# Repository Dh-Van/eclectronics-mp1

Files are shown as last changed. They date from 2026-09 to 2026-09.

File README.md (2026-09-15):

# ENGR 3430 Miniproject 1 – USB LED Flasher

A USB-stick style board that plugs into a USB-A port, regulates 5 V down to 3.3 V, and blinks a red LED with a 1 s period using an op-amp relaxation oscillator.

## Folder layout

| Folder | What's in it |
|---|---|
| `kicad/` | KiCad 10 project: schematic, PCB layout, project settings. `kicad/lib/` holds the custom symbol library (`Eclectronics.kicad_sym`) and footprints (`Eclectronics.pretty/`) for the USB plug, MCP1702 and MCP6021. The project's `sym-lib-table` / `fp-lib-table` point at these with `${KIPRJMOD}` paths, so the project opens on any machine with no extra setup. |
| `ltspice/` | LTspice simulation. `sim.asc` is the 500-run Monte Carlo of the oscillator period (1 % resistors, 5 % cap); `sim.log` has the measured period for every run. The 290 MB `sim.raw` waveform file is not committed – rerun `sim.asc` to regenerate it. |
| `docs/` | `MP1_report.md` / `MP1_report.pdf` (design choices + period analysis; `build_pdf.py` regenerates the PDF with lualatex), `MP1_BOM.csv`, `MP1_schematic.pdf`, the assignment PDF and the allowed parts list. |

## Key numbers

- Period: 1.000 s by hand calculation, 0.987 s mean in simulation, worst case -6.8 % / +7.1 % (spec is +/-10 %).
- Board: 2 layers, 16.1 mm x 14.0 mm, all parts on top, back side is a ground pour. DRC clean.

## Opening the project

Open `kicad/MP1.kicad_pro` in KiCad 10. Note: the LTspice sim names differ from the KiCad schematic (sim R4 = KiCad R5, sim R5 = KiCad R4, sim C1 = KiCad C4); see the report.

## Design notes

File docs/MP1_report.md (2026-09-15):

# MP1 – USB LED Flasher: Design Choices and Period Analysis

## 1. Overview

The board plugs straight into a USB-A port, drops the 5 V to 3.3 V, and uses an op-amp relaxation oscillator to blink a red LED with a 1 s period.

$$
\text{USB 5 V} \;\rightarrow\; \text{3.3 V regulator (U1)} \;\rightarrow\; \text{op-amp oscillator (U2)} \;\rightarrow\; \text{R6 + LED}
$$

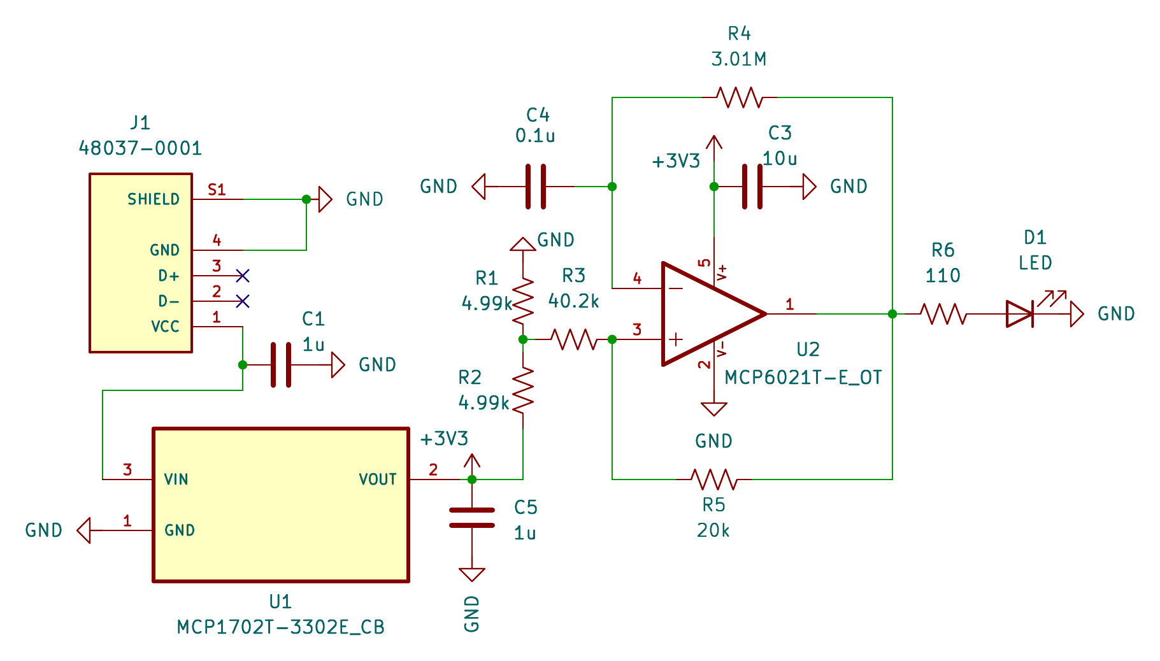
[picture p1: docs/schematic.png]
Circuit schematic. J1 is the USB-A plug, U1 the 3.3 V regulator, U2 the op-amp oscillator, D1 the LED. Full-size copy in .


Only parts from the provided parts list were allowed. That list has one connector, one regulator, two op-amps (single/dual versions of the same part), three LED colours, seven capacitor values and a set of 1% resistors. So most parts had no alternative; the real choices were the oscillator topology, the timing values, single vs. dual op-amp, and the LED colour. Part names are the KiCad ones (the LTspice sim uses sim R4 = KiCad R5, sim R5 = KiCad R4, sim C1 = KiCad C4).

**Why an op-amp oscillator.** There is no 555, microcontroller or crystal on the list, so the timer has to be built from the op-amp. A relaxation oscillator (Schmitt trigger + RC) needs one op-amp, one capacitor and a few resistors, gives a square wave that drives the LED directly, and has a simple period formula, which makes the tolerance analysis clean.

## 2. Power supply

- **J1 – Molex 48037-0001 USB-A plug.** Only connector on the list. Only VBUS and GND are used; D+/D- are left open since the board only takes power. Average draw is about 7 mA (1 mA op-amp + 12 mA LED half the time), well under the 100 mA a port gives without enumeration.
- **U1 – MCP1702 3.3 V LDO.** Only regulator on the list; fixed 3.3 V so no setting resistors; 250 mA rating vs. 7 mA used. Dissipation is about 12 mW.
- **C1 = 1 uF in, C3 = 10 uF out.** The MCP1702 datasheet needs at least 1 uF ceramic on both pins. The list only has 1 uF and 10 uF; the 10 uF goes on the output because that rail feeds everything and supplies the 12 mA LED step.
- **C5 = 1 uF op-amp bypass**, right at the V+ pin. The datasheet suggests 0.1-1 uF; 1 uF holds the pin steadier during the LED step, and it keeps the 0.1 uF (the only 5% cap) free for the timer.

## 3. Oscillator

**U2 – MCP6021.** Single op-amp in SOT-23-5. The MCP6022 is the same part but dual; only one is needed, so the single is smaller and leaves no unused op-amp. It works here because it runs on a single 3.3 V supply, has rail-to-rail output (the timing math assumes the output sits at the rails), has ~1 pA input current (negligible against the ~1 uA timing current), and can drive ~30 mA so no LED transistor is needed.

**How it works.** R1/R2 (4.99 k each) make a 1.65 V mid-rail reference $V_{mid}$, needed because there is no negative supply. R3 (40.2 k) and R5 (20 k) feed the + input from $V_{mid}$ and the output, giving two thresholds either side of $V_{mid}$. R4 (3.01 M) charges C4 (0.1 uF) on the - input from the output. When C4 crosses the upper threshold the output flips low and C4 discharges; when it crosses the lower threshold the output flips high again. The output is a square wave and the LED follows it.

**Why these values.**

- **C4 = 0.1 uF.** The period is proportional to $R_4 C_4$, so the cap tolerance goes straight into the period. On the list the 0.1 uF is 5% ("J" in the part number); the 1 uF and 10 uF are 10%, which would fail the spec (Section 5.3); the 1% C0G parts (1 nF and below) would need a 300 M resistor, and the list stops at 10 M.
- **R4 = 3.01 M.** Gives $R_4 C_4 = 0.301$ s and a period of 1.00 s with the thresholds below. 10 M would need thresholds within 20 mV of the rails; 2 M works but pushes the thresholds much closer to the rails than 3.01 M.
- **R3 = 40.2 k, R5 = 20 k.** Thresholds too close to the rails make the period sensitive to how close the output really gets to the rails; too close to $V_{mid}$ makes the cap swing small so offset (0.5 mV) and noise matter. The 2:1 ratio puts the thresholds about 0.5 V from each rail, a good compromise.
- **R1 = R2 = 4.99 k.** Equal values give exactly half the supply, so the two half-cycles are equal (50% duty). 4.99 k is stiff enough that R3 barely loads it, and wastes only 0.3 mA.

## 4. LED

**D1 red LED (LTST-C171KRKT), R6 = 110 Ohm.** Red has the lowest forward voltage (~2 V) of the three LEDs, so on 3.3 V it gets the most current; green/blue (~3 V) would only get a few mA. The LED is driven straight from the output (anode to op-amp, cathode to ground), so it is on for half of each period:

$$
I_{LED} = \frac{3.3 - V_f}{R_6} = \frac{3.3 - 2.0}{110} \approx 12\ \text{mA}
$$

That is bright, with margin under the LED's 20 mA and the op-amp's ~30 mA limits. The 12 mA load pulls the high output down by ~0.1-0.2 V; that makes the charge half slightly longer and the discharge half slightly shorter, and the two nearly cancel (about +0.1% on the period, duty 50% to 52%).

## 5. Period analysis

### 5.1 Thresholds and period

The divider gives $V_{mid} = 1.65$ V and looks like $R_1 \parallel R_2 = 2.5$ k in series with R3, so the effective resistor from $V_{mid}$ to the + input is $R_a = 40.2 + 2.5 = 42.7$ k. The + input is a weighted average of $V_{mid}$ (through $R_a$) and the output (through $R_5$):

$$
V_{high} = \frac{V_{mid} R_5 + 3.3\,R_a}{R_a + R_5} = 2.774\ \text{V}, \qquad
V_{low} = \frac{V_{mid} R_5}{R_a + R_5} = 0.526\ \text{V}
$$

These are symmetric about 1.65 V. Charging from $V_{low}$ to $V_{high}$ with the output at 3.3 V, and discharging back, each take

$$
t_{up} = R_4 C_4 \ln\!\left(\frac{3.3 - V_{low}}{3.3 - V_{high}}\right)
      = 0.301 \cdot \ln\!\left(\frac{2.774}{0.526}\right) = 0.500\ \text{s},
\qquad
t_{down} = R_4 C_4 \ln\!\left(\frac{V_{high}}{V_{low}}\right) = 0.500\ \text{s}
$$

$$
T = t_{up} + t_{down} = 2 R_4 C_4 \ln\!\left(\frac{1 + \beta}{1 - \beta}\right) = 1.000\ \text{s}, \qquad \beta = \frac{R_a}{R_a + R_5} = 0.681
$$

(Leaving out the divider's 2.5 k gives 0.971 s, so it matters.)

### 5.2 Sensitivity

| Part | Change | Effect on $T$ |
|---|---|---|
| R4 (3.01 M) | +1% | +1.00% |
| C4 (0.1 uF) | +5% | +5.00% |
| R3 (40.2 k) | +1% | +0.46% |
| R5 (20 k) | +1% | -0.48% |
| R1 or R2 | +1% | +0.01% |

The period is essentially $R_4 C_4$; the threshold resistors count about half; the divider barely matters because shifting $V_{mid}$ lengthens one half-cycle and shortens the other. With 1% resistors, almost the whole error budget is the 5% cap.

### 5.3 Worst case

Stacking every tolerance the same way: $T = 1.071$ s (+7.1%) or $T = 0.932$ s (-6.8%). Both are inside +/-10% with about 3% to spare. With a 10% cap the worst case would be about +/-12% and fail, which is why the 5% 0.1 uF was chosen. Other effects are small: output 25 mV short of the rails (<0.1%), LED load droop (+0.1%), 0.5 mV input offset (0.02%), 1 pA bias current (negligible), 100 ppm/C resistors over 20 C (0.2%).

### 5.4 Monte Carlo (LTspice)

The sim uses the generic `UniversalOpAmp2` (no MCP6021 model exists) on a 3.3 V single supply, `.ic V(vn)=0` for a repeatable start, and measures the time between the 2nd and 3rd rising edges to skip the startup transient. `.step param run 1 500 1` with `mc(value, 0.01)` on every resistor and `mc(0.1u, 0.05)` on C4 gives 500 runs with the real part tolerances.

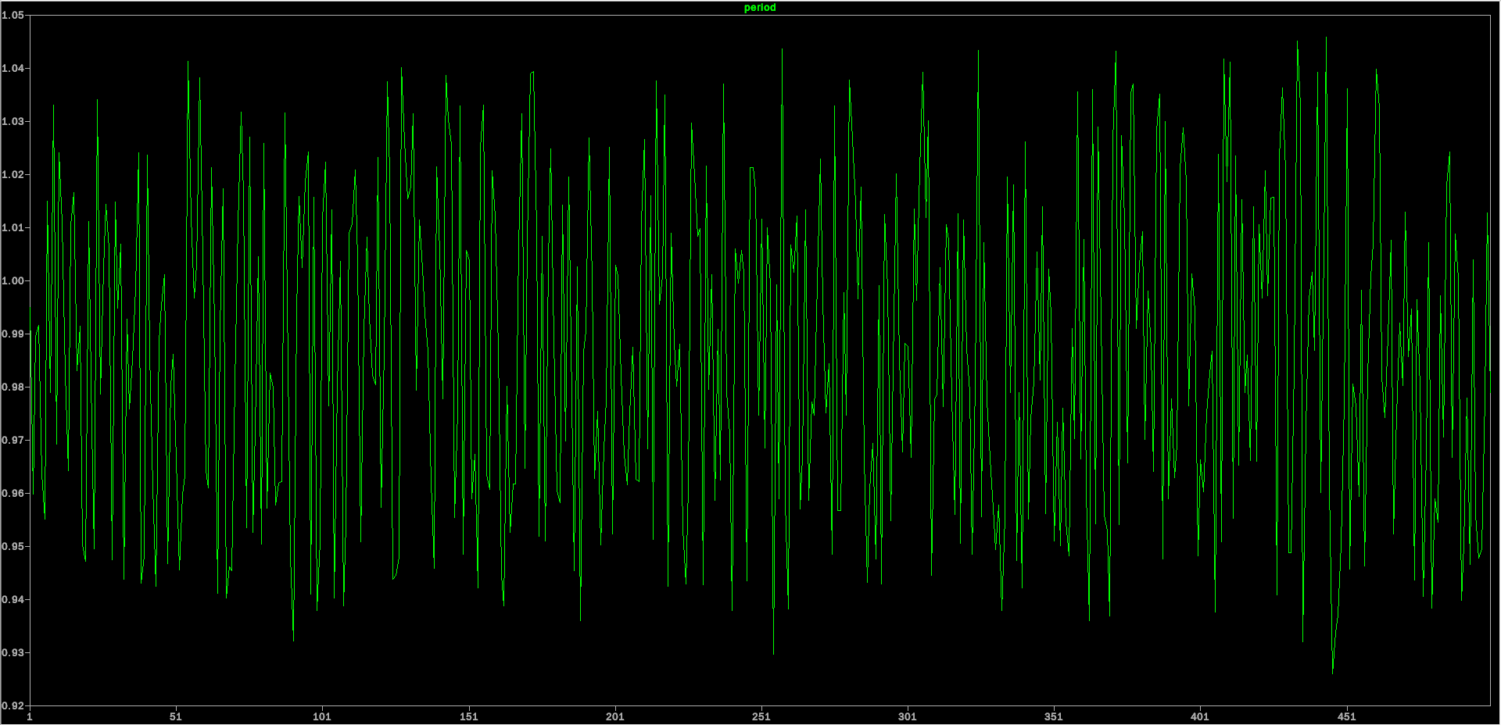
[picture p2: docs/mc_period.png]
Period of each Monte Carlo run. The y-axis spans 0.92-1.05 s; the +/-10% limits are 0.9 s and 1.1 s, so every run is inside.


| Statistic | Value |
|---|---|
| Mean period | 0.987 s |
| Std. deviation | 0.030 s |
| Minimum | 0.926 s (-7.4%) |
| Maximum | 1.046 s (+4.6%) |
| Runs inside 0.9-1.1 s | 500 / 500 |

The mean is 1.4% under the hand value because the modelled op-amp does not switch instantly or sit exactly on the rails. Every run is inside the window, matching the worst-case math.

## 6. PCB

- **Size.** 16.1 x 14.0 mm (225 mm^2). Height is set by the plug's shield pads plus edge clearance; width by fitting the parts in columns beside the plug. The board edge sits on the line the Molex footprint marks for it, and the plug is centred.
- **Placement.** U1 sits at J1's VBUS pin (2.4 mm trace) with C1 and C3 at its pins. U2 is in the middle with R3/C4 to its left, R5 above, R4 below, so the high-impedance - input trace is ~2 mm. C5 is at the V+ pin. R6 and D1 are at the far end so the LED is visible when plugged in.
- **Layers.** Two layers, all parts on top. Everything is routed on top; the back is an unbroken ground pour. Each ground pad reaches it through a via (0.8 mm / 0.4 mm drill); nearby grounds (U1, C1, C3, D1) share one. No via is in or touching a pad, to avoid paste wicking and tombstoning. The plug's through-hole pads join the pour with thermal reliefs. There is no top pour.
- **The one crossing.** The op-amp pinout forces one trace crossing. Instead of a back-side jumper (which would slot the ground plane), the 3.3 V feed to V+ runs between R4's pads.
- **Trace widths.** Power is 0.5 mm (20 mil), signals 0.2 mm (8 mil), 0.2 mm clearance, vias 31/16 mil, all above the 6 mil / 24-12 mil minimums. The one exception is the 3.3 V branch to the op-amp V+ pin: it narrows to 0.3-0.4 mm for ~4 mm because the gap between R4's pads is only 0.85 mm and a 0.5 mm trace would violate clearance. That branch carries about 1 mA, so it makes no difference.
- **Silkscreen / fab.** 0.8 mm reference designators kept off all pads; the plug's off-board silk outline removed; F.Fab has outlines, references and values for assembly; the back silk has the board name, author and revision.
- **Checks.** DRC: 0 errors, 0 warnings, 0 unconnected. Schematic/PCB parity clean. Footprints are imperial 0603/0805, SOT-23-3 and SOT-23-5 as on the parts list. IC pin numbers match the datasheets (MCP1702: 1 GND, 2 VOUT, 3 VIN; MCP6021: 1 OUT, 2 VSS, 3 IN+, 4 IN-, 5 VDD).

## 7. Bill of materials

All parts are from the provided parts list: 12 line items, 15 parts. (Also provided as `MP1_BOM.csv`.)

| # | Ref | Qty | Value | Description | Manufacturer Part # | Digi-Key # | Tol. | Notes |
|---|---|---|---|---|---|---|---|---|
| 1 | J1 | 1 | 48037-0001 | CONN PLUG USB 4POS RT ANG PCB | 0480370001 | WM17117-ND |  | USB-A plug; only VBUS and GND used |
| 2 | U1 | 1 | MCP1702T-3302E/CB | IC REG LIN 3.3V 250MA SOT23A-3 | MCP1702T-3302E/CB | MCP1702T-3302E/CBCT-ND |  | 3.3 V LDO regulator |
| 3 | U2 | 1 | MCP6021T-E/OT | IC OPAMP GP 10MHZ RRO SOT23-5 | MCP6021T-E/OT | MCP6021T-E/OTCT-ND |  | Rail-to-rail op-amp (oscillator) |
| 4 | D1 | 1 | LED | LED RED CLEAR 0805 SMD | LTST-C171KRKT | 160-1427-1-ND |  | Red LED |
| 5 | C1,C5 | 2 | 1u | CAP CER 1UF 25V X7R 0603 | C0603C105K3RACTU | 399-7376-1-ND | 10% | C1 = LDO input cap; C5 = op-amp bypass |
| 6 | C3 | 1 | 10u | CAP CER 10UF 16V X5R 0603 | GRT188R61C106KE13D | 490-12317-1-ND | 10% | LDO output / bulk cap |
| 7 | C4 | 1 | 0.1u | CAP CER 0.1UF 50V X7R 0603 | CC0603JRX7R9BB104 | 311-1779-1-ND | 5% | Timing capacitor |
| 8 | R1,R2 | 2 | 4.99k | RES SMD 4.99K OHM 1% 1/10W 0603 | RC0603FR-074K99L | 311-4.99KHRCT-ND | 1% | Mid-rail divider |
| 9 | R3 | 1 | 40.2k | RES SMD 40.2K OHM 1% 1/10W 0603 | RC0603FR-0740K2L | 311-40.2KHRCT-ND | 1% | Threshold resistor |
| 10 | R4 | 1 | 3.01M | RES SMD 3.01M OHM 1% 1/10W 0603 | RC0603FR-073M01L | 311-3.01MHRCT-ND | 1% | Timing resistor |
| 11 | R5 | 1 | 20k | RES SMD 20K OHM 1% 1/10W 0603 | RC0603FR-0720KL | 311-20.0KHRCT-ND | 1% | Threshold / positive feedback resistor |
| 12 | R6 | 1 | 110 | RES SMD 110 OHM 1% 1/10W 0603 | RC0603FR-07110RL | 311-110HRCT-ND | 1% | LED current-limit resistor |

**Project files.** All KiCad design files, the custom symbol/footprint library, the LTspice simulation, this report and the BOM are at:

https://github.com/Dh-Van/eclectronics-mp1

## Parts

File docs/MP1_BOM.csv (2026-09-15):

Item | Reference | Qty | Value | Description | Package | Manufacturer | Manufacturer Part # | Digi-Key Part # | Tolerance | Notes
1 | J1 | 1 | 48037-0001 | CONN PLUG USB 4POS RT ANG PCB | Through-hole right angle | Molex | 0480370001 | WM17117-ND |  | USB-A plug; only VBUS and GND used
2 | U1 | 1 | MCP1702T-3302E/CB | IC REG LIN 3.3V 250MA SOT23A-3 | SOT-23-3 | Microchip | MCP1702T-3302E/CB | MCP1702T-3302E/CBCT-ND |  | 3.3 V LDO regulator
3 | U2 | 1 | MCP6021T-E/OT | IC OPAMP GP 10MHZ RRO SOT23-5 | SOT-23-5 | Microchip | MCP6021T-E/OT | MCP6021T-E/OTCT-ND |  | Rail-to-rail op-amp (oscillator)
4 | D1 | 1 | LED | LED RED CLEAR 0805 SMD | 0805 | Lite-On | LTST-C171KRKT | 160-1427-1-ND |  | Red LED
5 | C1,C5 | 2 | 1u | CAP CER 1UF 25V X7R 0603 | 0603 | KEMET | C0603C105K3RACTU | 399-7376-1-ND | 10% | C1 = LDO input cap; C5 = op-amp bypass
6 | C3 | 1 | 10u | CAP CER 10UF 16V X5R 0603 | 0603 | Murata | GRT188R61C106KE13D | 490-12317-1-ND | 10% | LDO output / bulk cap
7 | C4 | 1 | 0.1u | CAP CER 0.1UF 50V X7R 0603 | 0603 | Yageo | CC0603JRX7R9BB104 | 311-1779-1-ND | 5% | Timing capacitor
8 | R1,R2 | 2 | 4.99k | RES SMD 4.99K OHM 1% 1/10W 0603 | 0603 | Yageo | RC0603FR-074K99L | 311-4.99KHRCT-ND | 1% | Mid-rail divider
9 | R3 | 1 | 40.2k | RES SMD 40.2K OHM 1% 1/10W 0603 | 0603 | Yageo | RC0603FR-0740K2L | 311-40.2KHRCT-ND | 1% | Threshold resistor
10 | R4 | 1 | 3.01M | RES SMD 3.01M OHM 1% 1/10W 0603 | 0603 | Yageo | RC0603FR-073M01L | 311-3.01MHRCT-ND | 1% | Timing resistor
11 | R5 | 1 | 20k | RES SMD 20K OHM 1% 1/10W 0603 | 0603 | Yageo | RC0603FR-0720KL | 311-20.0KHRCT-ND | 1% | Threshold / positive feedback resistor
12 | R6 | 1 | 110 | RES SMD 110 OHM 1% 1/10W 0603 | 0603 | Yageo | RC0603FR-07110RL | 311-110HRCT-ND | 1% | LED current-limit resistor

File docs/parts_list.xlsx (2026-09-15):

Part Type | Part Description | Digikey Catalog # | Manufacturer Part #
Connectors | CONN PLUG USB 4POS RT ANG PCB | WM17117-ND | 0480370001
ICs | IC REG LIN 3.3V 250MA SOT23A-3 | MCP1702T-3302E/CBCT-ND | MCP1702T-3302E/CB
 | IC OPAMP GP 10MHZ RRO 8TSSOP | MCP6022T-I/STCT-ND | MCP6022T-I/ST
 | IC OPAMP GP 10MHZ RRO SOT23-5 | MCP6021T-E/OTCT-ND | MCP6021T-E/OT
LEDs | LED GREEN CLEAR 0805 SMD | 160-1887-1-ND | LTST-C170TGKT
 | LED RED CLEAR 0805 SMD | 160-1427-1-ND | LTST-C171KRKT
 | LED BLUE CLEAR 0805 SMD | 160-1579-1-ND | LTST-C170TBKT
Capacitors | CAP CER 10UF 16V X5R 0603 | 490-12317-1-ND | GRT188R61C106KE13D
 | CAP CER 1UF 25V X7R 0603 | 399-7376-1-ND | C0603C105K3RACTU
 | CAP CER 0.1UF 50V X7R 0603 | 311-1779-1-ND | CC0603JRX7R9BB104
 | CAP CER 10000PF 50V X7R 0603 | 399-1092-1-ND | C0603C103J5RACTU
 | CAP CER 1000PF 50V C0G/NP0 0603 | 490-6377-1-ND | GRM1885C1H102FA01J
 | CAP CER 100PF 50V C0G/NP0 0603 | 1276-2159-1-ND | CL10C101FB8NNNC
 | CAP CER 10PF 50V C0G/NP0 0603 | 490-9682-1-ND | GRM1885C1H100FA01J
Resistors | RES SMD 10 OHM 1% 1/10W 0603 | 311-10.0HRCT-ND | RC0603FR-0710RL
 | RES SMD 11 OHM 1% 1/10W 0603 | 311-11.0HRCT-ND | RC0603FR-0711RL
 | RES SMD 12.7 OHM 1% 1/10W 0603 | 311-12.7HRCT-ND | RC0603FR-0712R7L
 | RES SMD 14.3 OHM 1% 1/10W 0603 | 311-14.3HRCT-ND | RC0603FR-0714R3L
 | RES SMD 15.8 OHM 1% 1/10W 0603 | 311-15.8HRCT-ND | RC0603FR-0715R8L
 | RES SMD 20 OHM 1% 1/10W 0603 | 311-20.0HRCT-ND | RC0603FR-0720RL
 | RES SMD 30.1 OHM 1% 1/10W 0603 | 311-30.1HRCT-ND | RC0603FR-0730R1L
 | RES SMD 31.6 OHM 1% 1/10W 0603 | 311-31.6HRCT-ND | RC0603FR-0731R6L
 | RES SMD 40.2 OHM 1% 1/10W 0603 | 311-40.2HRCT-ND | RC0603FR-0740R2L
 | RES SMD 47.5 OHM 1% 1/10W 0603 | 311-47.5HRCT-ND | RC0603FR-0747R5L
 | RES SMD 49.9 OHM 1% 1/10W 0603 | 311-49.9HRCT-ND | RC0603FR-0749R9L
 | RES SMD 60.4 OHM 1% 1/10W 0603 | 311-60.4HRCT-ND | RC0603FR-0760R4L
 | RES SMD 63.4 OHM 1% 1/10W 0603 | 311-63.4HRCT-ND | RC0603FR-0763R4L
 | RES SMD 69.8 OHM 1% 1/10W 0603 | 311-69.8HRCT-ND | RC0603FR-0769R8L
 | RES SMD 80.6 OHM 1% 1/10W 0603 | 311-80.6HRCT-ND | RC0603FR-0780R6L
 | RES SMD 90.9 OHM 1% 1/10W 0603 | 311-90.9HRCT-ND | RC0603FR-0790R9L
 | RES SMD 95.3 OHM 1% 1/10W 0603 | 311-95.3HRCT-ND | RC0603FR-0795R3L
 | RES SMD 100 OHM 1% 1/10W 0603 | 311-100HRCT-ND | RC0603FR-07100RL
 | RES SMD 110 OHM 1% 1/10W 0603 | 311-110HRCT-ND | RC0603FR-07110RL
 | RES SMD 127 OHM 1% 1/10W 0603 | 311-127HRCT-ND | RC0603FR-07127RL
 | RES SMD 143 OHM 1% 1/10W 0603 | 311-143HRCT-ND | RC0603FR-07143RL
 | RES SMD 158 OHM 1% 1/10W 0603 | 311-158HRCT-ND | RC0603FR-07158RL
 | RES SMD 200 OHM 1% 1/10W 0603 | 311-200HRCT-ND | RC0603FR-07200RL
 | RES SMD 301 OHM 1% 1/10W 0603 | 311-301HRCT-ND | RC0603FR-07301RL
 | RES SMD 316 OHM 1% 1/10W 0603 | 311-316HRCT-ND | RC0603FR-07316RL
 | RES SMD 402 OHM 1% 1/10W 0603 | 311-402HRCT-ND | RC0603FR-07402RL
 | RES SMD 475 OHM 1% 1/10W 0603 | 311-475HRCT-ND | RC0603FR-07475RL
 | RES SMD 499 OHM 1% 1/10W 0603 | 311-499HRCT-ND | RC0603FR-07499RL
 | RES SMD 604 OHM 1% 1/10W 0603 | 311-604HRCT-ND | RC0603FR-07604RL
 | RES SMD 634 OHM 1% 1/10W 0603 | 311-634HRCT-ND | RC0603FR-07634RL
 | RES SMD 698 OHM 1% 1/10W 0603 | 311-698HRCT-ND | RC0603FR-07698RL
 | RES SMD 806 OHM 1% 1/10W 0603 | 311-806HRCT-ND | RC0603FR-07806RL
 | RES SMD 909 OHM 1% 1/10W 0603 | 311-909HRCT-ND | RC0603FR-07909RL
 | RES SMD 953 OHM 1% 1/10W 0603 | 311-953HRCT-ND | RC0603FR-07953RL
 | RES SMD 1K OHM 1% 1/10W 0603 | 311-1.00KHRCT-ND | RC0603FR-071KL
 | RES SMD 1.1K OHM 1% 1/10W 0603 | 311-1.10KHRCT-ND | RC0603FR-071K1L
 | RES SMD 1.27K OHM 1% 1/10W 0603 | 311-1.27KHRCT-ND | RC0603FR-071K27L
 | RES SMD 1.43K OHM 1% 1/10W 0603 | 311-1.43KHRCT-ND | RC0603FR-071K43L
 | RES SMD 1.58K OHM 1% 1/10W 0603 | 311-1.58KHRCT-ND | RC0603FR-071K58L
 | RES SMD 2K OHM 1% 1/10W 0603 | 311-2.00KHRCT-ND | RC0603FR-072KL
 | RES SMD 3.01K OHM 1% 1/10W 0603 | 311-3.01KHRCT-ND | RC0603FR-073K01L
 | RES SMD 3.16K OHM 1% 1/10W 0603 | 311-3.16KHRCT-ND | RC0603FR-073K16L
 | RES SMD 4.02K OHM 1% 1/10W 0603 | 311-4.02KHRCT-ND | RC0603FR-074K02L
 | RES SMD 4.75K OHM 1% 1/10W 0603 | 311-4.75KHRCT-ND | RC0603FR-074K75L
 | RES SMD 4.99K OHM 1% 1/10W 0603 | 311-4.99KHRCT-ND | RC0603FR-074K99L
 | RES SMD 6.04K OHM 1% 1/10W 0603 | 311-6.04KHRCT-ND | RC0603FR-076K04L
 | RES SMD 6.34K OHM 1% 1/10W 0603 | 311-6.34KHRCT-ND | RC0603FR-076K34L
 | RES SMD 6.98K OHM 1% 1/10W 0603 | 311-6.98KHRCT-ND | RC0603FR-076K98L
 | RES SMD 8.06K OHM 1% 1/10W 0603 | 311-8.06KHRCT-ND | RC0603FR-078K06L
 | RES SMD 9.09K OHM 1% 1/10W 0603 | 311-9.09KHRCT-ND | RC0603FR-079K09L
 | RES SMD 9.53K OHM 1% 1/10W 0603 | 311-9.53KHRCT-ND | RC0603FR-079K53L
 | RES SMD 10K OHM 1% 1/10W 0603 | 311-10.0KHRCT-ND | RC0603FR-0710KL
 | RES SMD 11K OHM 1% 1/10W 0603 | 311-11.0KHRCT-ND | RC0603FR-0711KL
 | RES SMD 12.7K OHM 1% 1/10W 0603 | 311-12.7KHRCT-ND | RC0603FR-0712K7L
 | RES SMD 14.3K OHM 1% 1/10W 0603 | 311-14.3KHRCT-ND | RC0603FR-0714K3L
 | RES SMD 15.8K OHM 1% 1/10W 0603 | 311-15.8KHRCT-ND | RC0603FR-0715K8L
 | RES SMD 20K OHM 1% 1/10W 0603 | 311-20.0KHRCT-ND | RC0603FR-0720KL
 | RES SMD 30.1K OHM 1% 1/10W 0603 | 311-30.1KHRCT-ND | RC0603FR-0730K1L
 | RES SMD 31.6K OHM 1% 1/10W 0603 | 311-31.6KHRCT-ND | RC0603FR-0731K6L
 | RES SMD 40.2K OHM 1% 1/10W 0603 | 311-40.2KHRCT-ND | RC0603FR-0740K2L
 | RES SMD 47.5K OHM 1% 1/10W 0603 | 311-47.5KHRCT-ND | RC0603FR-0747K5L
 | RES SMD 49.9K OHM 1% 1/10W 0603 | 311-49.9KHRCT-ND | RC0603FR-0749K9L
 | RES SMD 60.4K OHM 1% 1/10W 0603 | 311-60.4KHRCT-ND | RC0603FR-0760K4L
 | RES SMD 63.4K OHM 1% 1/10W 0603 | 311-63.4KHRCT-ND | RC0603FR-0763K4L
 | RES SMD 69.8K OHM 1% 1/10W 0603 | 311-69.8KHRCT-ND | RC0603FR-0769K8L
 | RES SMD 80.6K OHM 1% 1/10W 0603 | 311-80.6KHRCT-ND | RC0603FR-0780K6L
 | RES SMD 90.9K OHM 1% 1/10W 0603 | 311-90.9KHRCT-ND | RC0603FR-0790K9L
 | RES SMD 95.3K OHM 1% 1/10W 0603 | 311-95.3KHRCT-ND | RC0603FR-0795K3L
 | RES SMD 100K OHM 1% 1/10W 0603 | 311-100KHRCT-ND | RC0603FR-07100KL
 | RES SMD 110K OHM 1% 1/10W 0603 | 311-110KHRCT-ND | RC0603FR-07110KL
 | RES SMD 127K OHM 1% 1/10W 0603 | 311-127KHRCT-ND | RC0603FR-07127KL
 | RES SMD 143K OHM 1% 1/10W 0603 | 311-143KHRCT-ND | RC0603FR-07143KL
 | RES SMD 158K OHM 1% 1/10W 0603 | 311-158KHRCT-ND | RC0603FR-07158KL
 | RES SMD 200K OHM 1% 1/10W 0603 | 311-200KHRCT-ND | RC0603FR-07200KL
 | RES SMD 301K OHM 1% 1/10W 0603 | 311-301KHRCT-ND | RC0603FR-07301KL
 | RES SMD 316K OHM 1% 1/10W 0603 | 311-316KHRCT-ND | RC0603FR-07316KL
 | RES SMD 402K OHM 1% 1/10W 0603 | 311-402KHRCT-ND | RC0603FR-07402KL
 | RES SMD 475K OHM 1% 1/10W 0603 | 311-475KHRCT-ND | RC0603FR-07475KL
 | RES SMD 499K OHM 1% 1/10W 0603 | 311-499KHRCT-ND | RC0603FR-07499KL
 | RES SMD 604K OHM 1% 1/10W 0603 | 311-604KHRCT-ND | RC0603FR-07604KL
 | RES SMD 634K OHM 1% 1/10W 0603 | 311-634KHRCT-ND | RC0603FR-07634KL
 | RES SMD 698K OHM 1% 1/10W 0603 | 311-698KHRCT-ND | RC0603FR-07698KL
 | RES SMD 806K OHM 1% 1/10W 0603 | 311-806KHRCT-ND | RC0603FR-07806KL
 | RES SMD 909K OHM 1% 1/10W 0603 | 311-909KHRCT-ND | RC0603FR-07909KL
 | RES SMD 953K OHM 1% 1/10W 0603 | 311-953KHRCT-ND | RC0603FR-07953KL
 | RES SMD 1M OHM 1% 1/10W 0603 | 311-1.00MHRCT-ND | RC0603FR-071ML
 | RES SMD 2M OHM 1% 1/10W 0603 | 311-2.00MHRCT-ND | RC0603FR-072ML
 | RES SMD 3.01M OHM 1% 1/10W 0603 | 311-3.01MHRCT-ND | RC0603FR-073M01L
 | RES SMD 10M OHM 1% 1/10W 0603 | 311-10.0MHRCT-ND | RC0603FR-0710ML

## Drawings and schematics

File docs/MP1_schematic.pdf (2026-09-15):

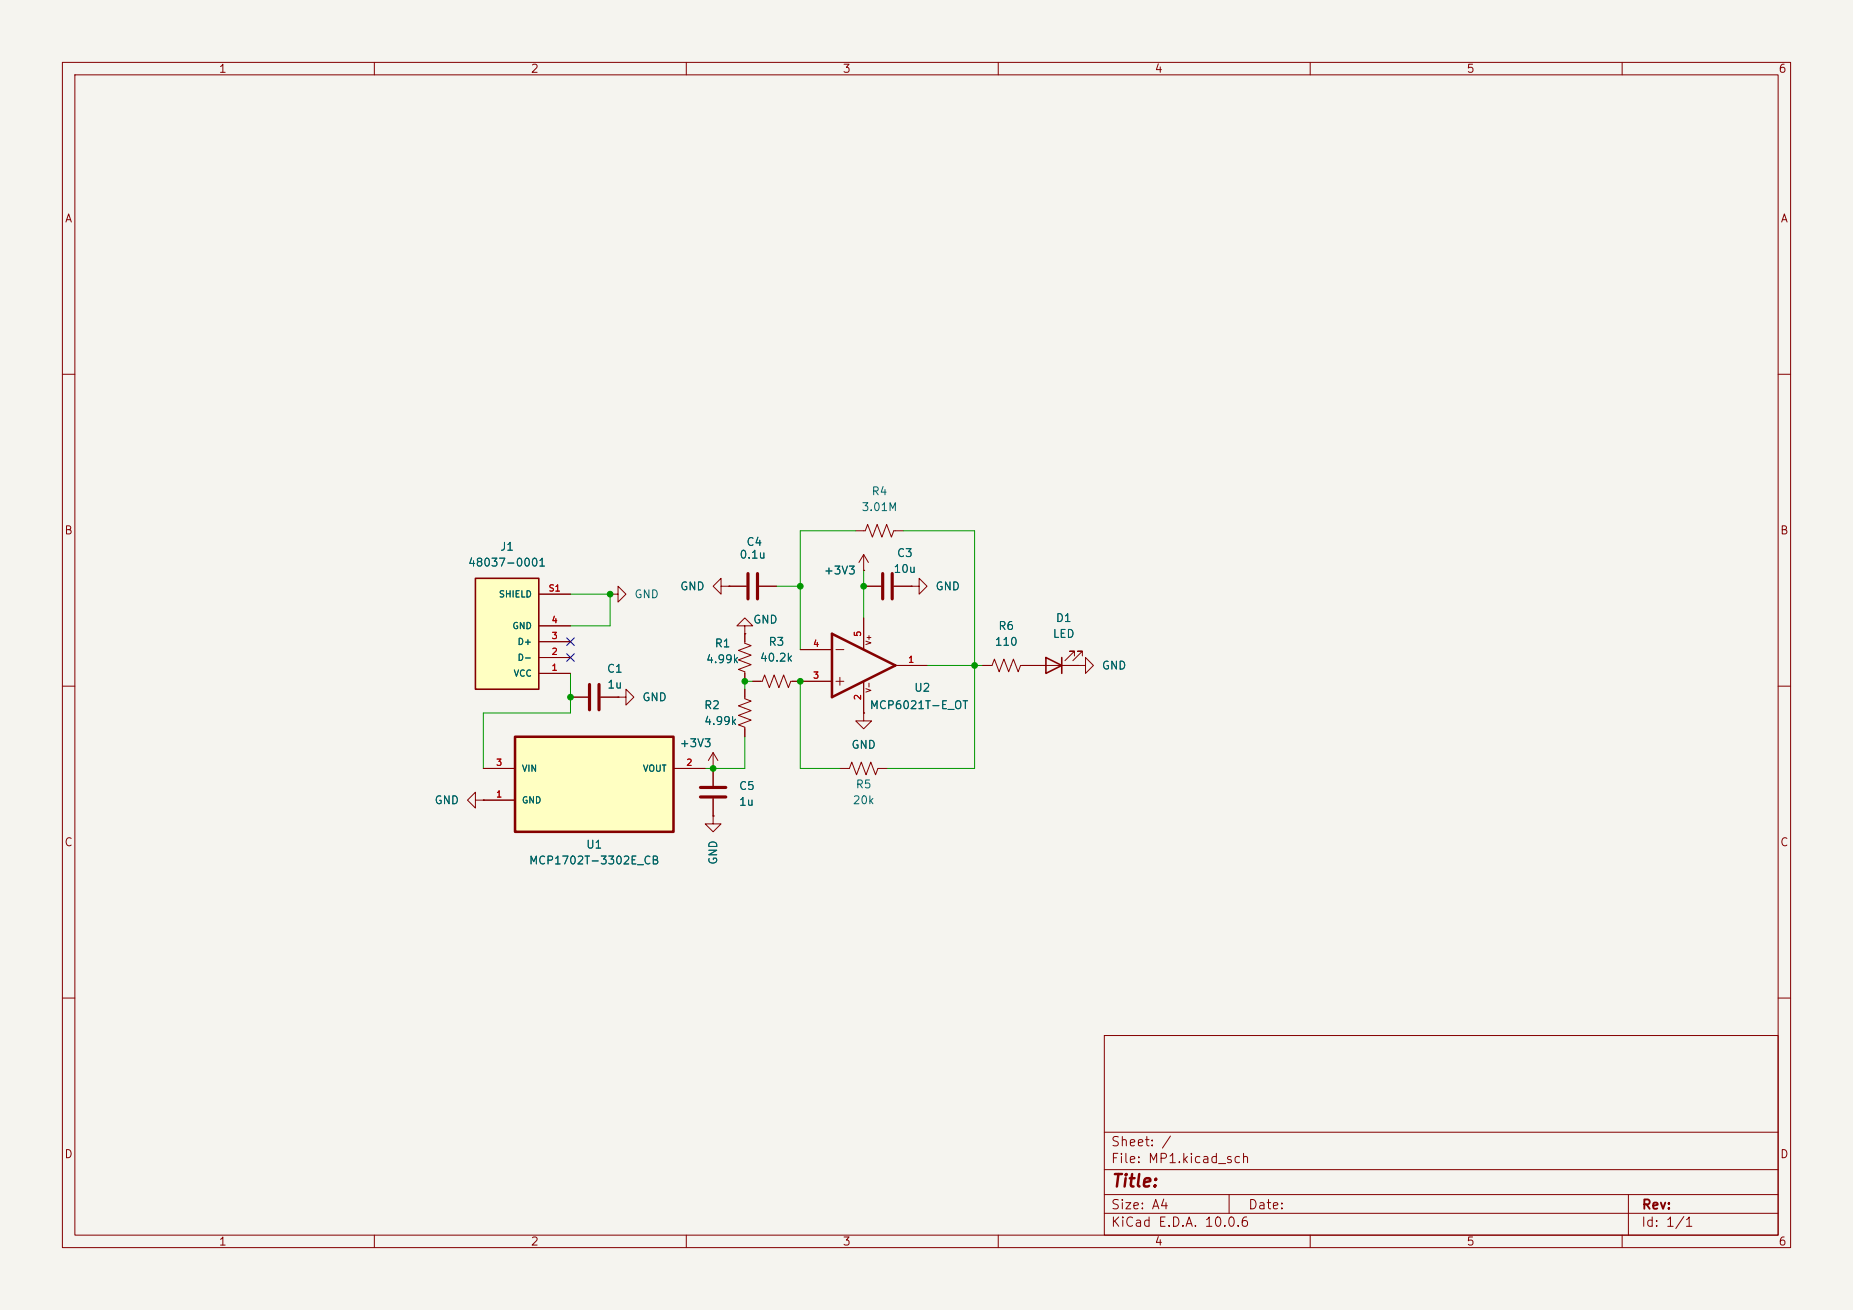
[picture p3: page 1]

Size: A4 | Rev:
KiCad E.D.A. 10.0.6 | Id: 1/1

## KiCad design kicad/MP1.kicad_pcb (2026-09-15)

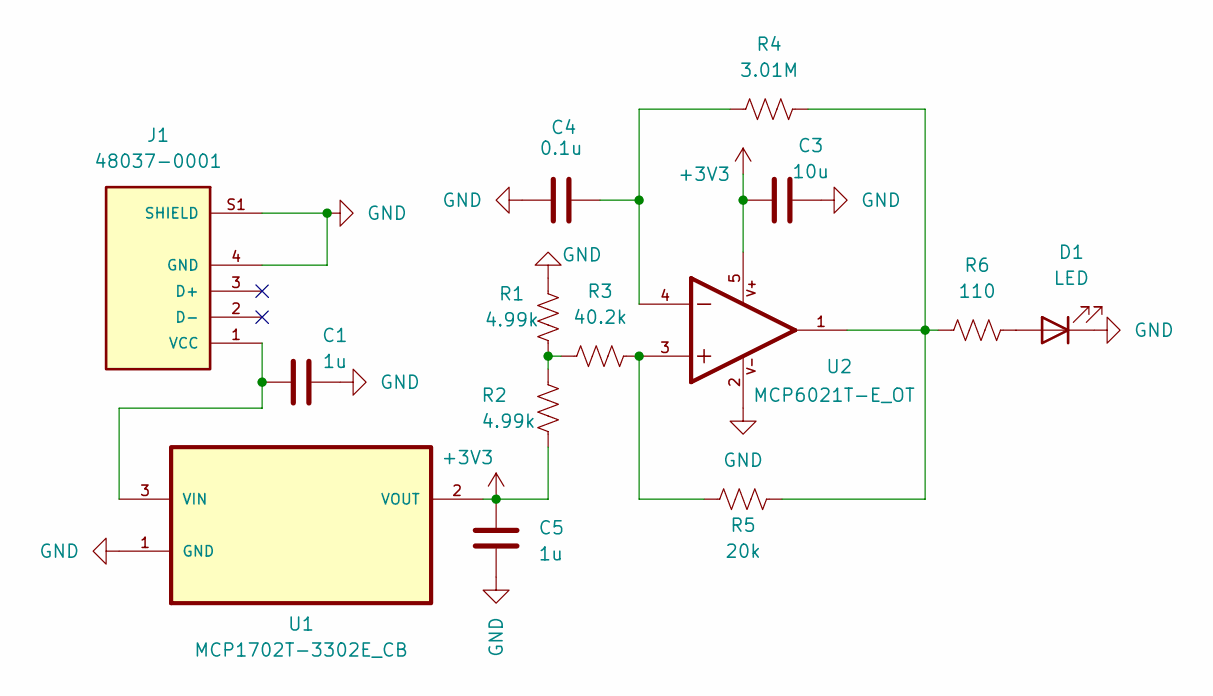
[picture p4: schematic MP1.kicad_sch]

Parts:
C1, C5: 1u; C_0603_1608Metric
C3: 10u; C_0603_1608Metric
C4: 0.1u; C_0603_1608Metric
D1: LED; LED_0805_2012Metric
J1: 48037-0001; MOLEX_48037-0001; PARTREV D
R1, R2: 4.99k; R_0603_1608Metric
R3: 40.2k; R_0603_1608Metric
R4: 3.01M; R_0603_1608Metric
R5: 20k; R_0603_1608Metric
R6: 110; R_0603_1608Metric
U1: MCP1702T-3302E_CB; SOT95P255X145-3N; MPN MCP1702T-3302E/CB; DigiKey_Part_Number MCP1702T-3302E/CBCT-ND
U2: MCP6021T-E_OT; SOT95P280X145-5N; PARTREV E

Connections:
+3V3: C3.1, C5.1, R2.2, U1.2 (VOUT), U2.5
GND: C1.2, C3.2, C4.1, C5.2, D1.1 (K), J1.4 (GND), J1.S1 (SHIELD), J1.S2 (SHIELD), R1.1, U1.1 (GND), U2.2
unnamed: C4.2, R4.1, U2.4
unnamed: D1.2 (A), R6.2
unnamed: C1.1, J1.1 (VCC), U1.3 (VIN)
unnamed: R1.2, R2.1, R3.1
unnamed: R3.2, R5.1, U2.3
unnamed: R4.2, R5.2, R6.1, U2.1

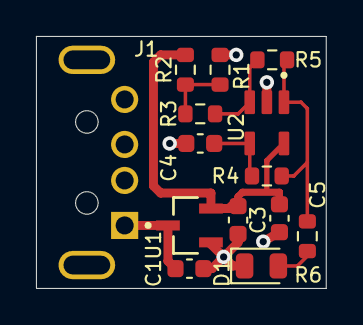
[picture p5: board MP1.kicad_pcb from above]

Board: 2 copper layers, 16.1 x 14.0 mm, 14 parts (0 on the bottom side), 8 nets.

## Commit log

2026-09-15 ENGR 3430 MP1: USB LED flasher – KiCad project, LTspice sim, report and BOM
    Self-contained KiCad 10 project with project-local symbol/footprint
    libraries, LTspice Monte Carlo simulation of the oscillator period,
    design report (with BOM table), BOM CSV, schematic PDF, assignment and
    parts list.
    [MP1.kicad_pcb, MP1.kicad_sch, MP1_BOM.csv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]
2026-09-15 Tidy silkscreen and fab layers; full design-choice report; drop unused LTspice draft
    - F.SilkS: labels off pads, plug's off-board body outline removed
    - F.Fab: 0.5 mm values beside parts, reference text in IC/connector bodies
    - B.SilkS: title / author / revision block
    - Library footprints for J1, U1, U2 updated to match the board
    - Report: every circuit and PCB design choice explained, BOM table added
    [MP1.kicad_pcb]
2026-09-15 Report PDF: BOM as portrait table, link kept with its section
2026-09-15 Report: add schematic figure
